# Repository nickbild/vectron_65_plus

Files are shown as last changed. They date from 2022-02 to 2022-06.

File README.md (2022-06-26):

# Vectron 65 Plus

The Vectron 65 Plus is a 6502 CPU-based computer with keyboard support that can run BASIC.  It is highly extensible via 32 GPIO pins.

At present, I have built the following peripherals for the computer:
- [Vectron VGA Plus v2](https://github.com/nickbild/vectron_vga_plus_v2) - VGA output with pixel-level control
- [Vectron VGA Plus Text Mode](https://github.com/nickbild/vectron_vga_plus_text_mode) - Add-on for Vectron VGA Plus v2 that simplifies displaying text on screen
- [Vectron Sound Plus](https://github.com/nickbild/vectron_sound_plus) - Audio output with the AY-3-8910 sound generator chip

Read on for demonstrations of each of these add-ons.

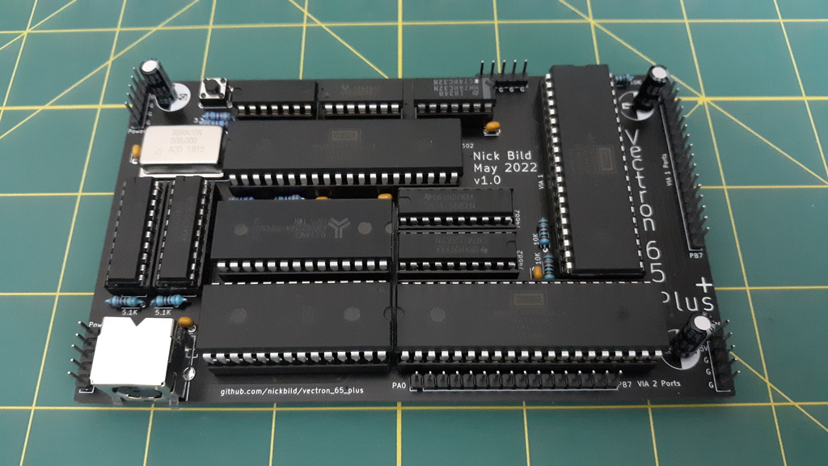
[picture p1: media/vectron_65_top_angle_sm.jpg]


This is an enhanced version of my [Vectron 65](https://github.com/nickbild/vectron_65) computer.

## How It Works

At the heart of the system is a WDC 65C02 CPU running at 8 MHz.  32 KB of SRAM is available, and a 32 KB ROM chip stores the program to execute (you can burn the ROM with [my Arduino code](https://github.com/nickbild/eeprom_burner_mega)).  A pair of 6522 VIA chips add a total of 32 GPIO pins to interface with external peripherals.  A PS/2 connector is present to support a keyboard (or a mouse, in theory, though I haven't tried one yet) — the clock and data lines are routed to GPIO pins.

This is the circuit design:



## Media

Here, the Vectron 65 Plus (left) is running TinyBASIC.  On the right, [Vectron VGA Plus Text Mode](https://github.com/nickbild/vectron_vga_plus_text_mode) is stacked on top of [Vectron VGA Plus v2](https://github.com/nickbild/vectron_vga_plus_v2) to provide a text mode VGA display output ([6502 code here](https://github.com/nickbild/vectron_65_plus/blob/main/os_vvga.asm)):

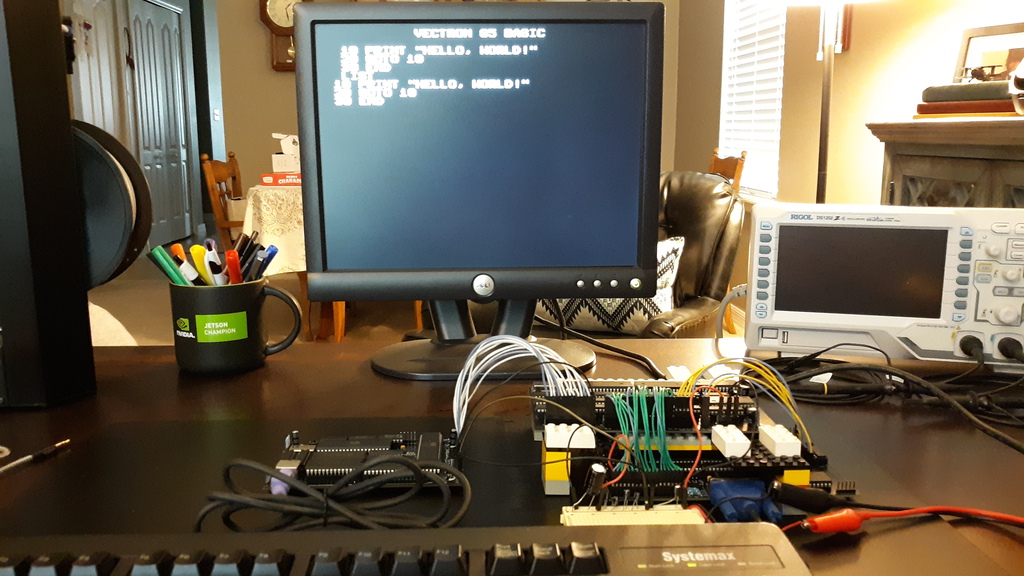
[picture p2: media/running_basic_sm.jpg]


In this example, the Vectron 65 Plus (right) is hooked up to [Vectron VGA Plus v2](https://github.com/nickbild/vectron_vga_plus_v2) to output some bitmap graphics ([6502 code here](https://github.com/nickbild/vectron_65_plus/blob/main/pacman.asm)):

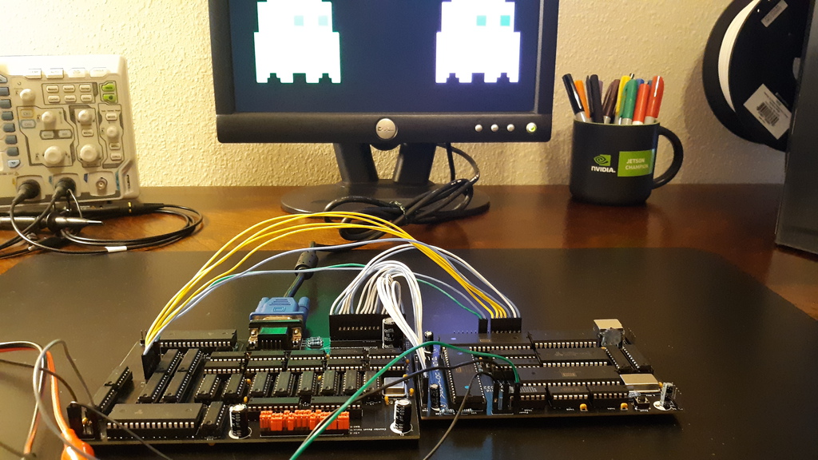
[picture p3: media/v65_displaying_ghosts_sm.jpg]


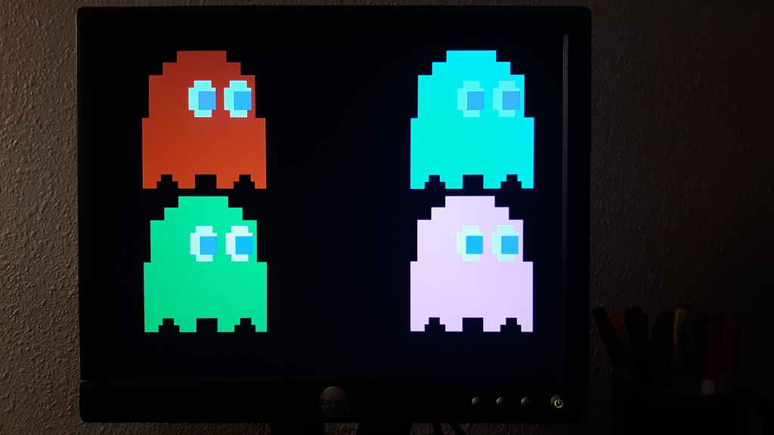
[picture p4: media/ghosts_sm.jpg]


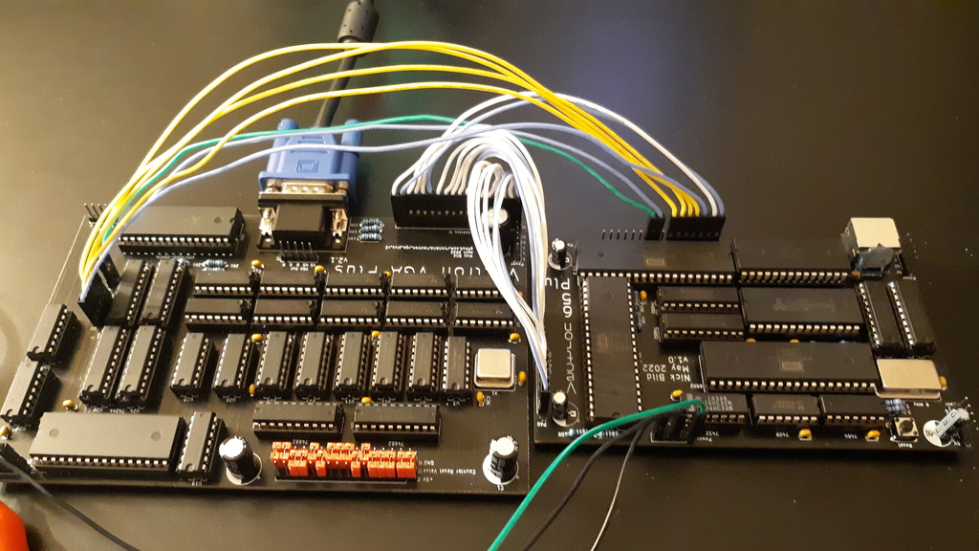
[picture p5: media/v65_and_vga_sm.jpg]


And for audio, I added in the [Vectron Sound Plus](https://github.com/nickbild/vectron_sound_plus) module:



You can download an [MP3 here](https://github.com/nickbild/vectron_sound_plus/blob/main/media/vectron_65_audio.mp3?raw=true) of a tune I made with it.

And a few more pictures:

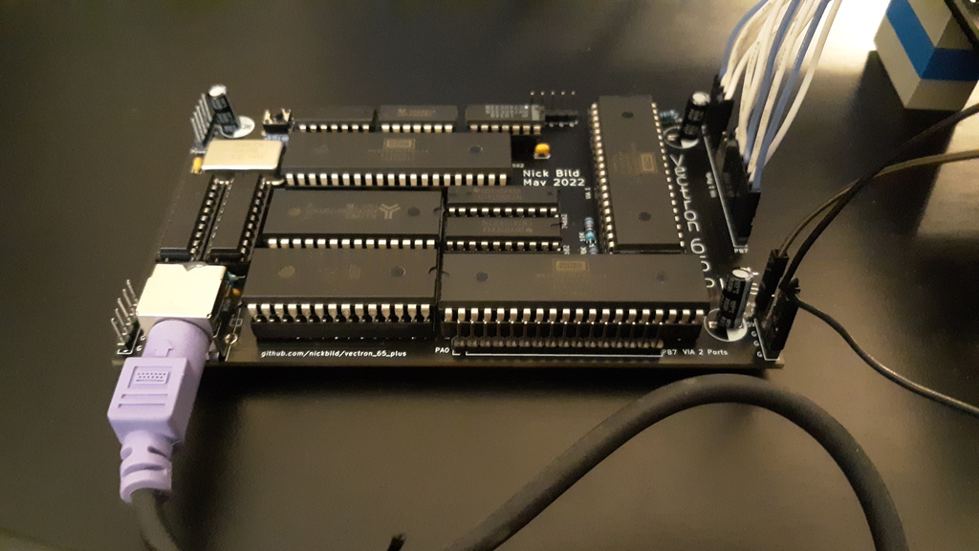
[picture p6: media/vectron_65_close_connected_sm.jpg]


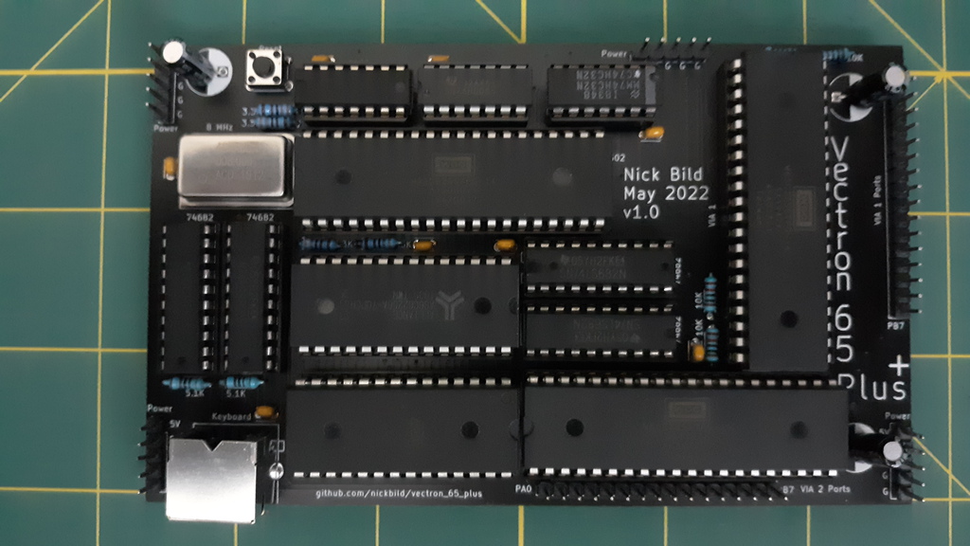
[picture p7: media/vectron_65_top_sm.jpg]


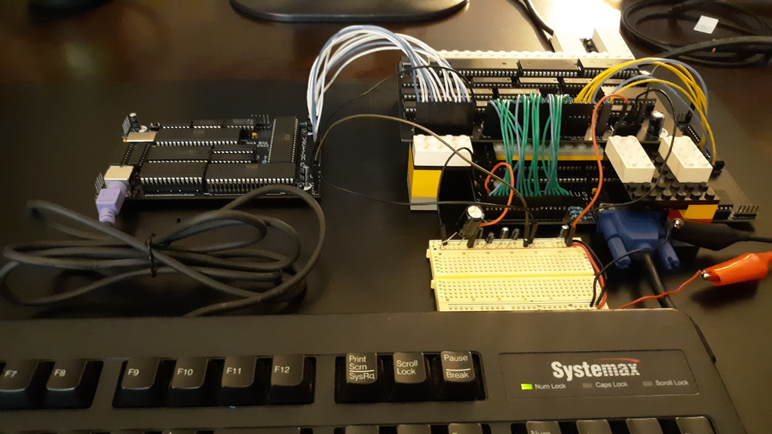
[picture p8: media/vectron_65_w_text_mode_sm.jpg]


## Bill of Materials

- 1 x 65C02 CPU
- 2 x 6522 VIA
- 1 x 28C256 ROM
- 1 x AS6C62256A RAM
- 4 x 74682
- 1 x 7404
- 1 x 7408
- 1 x 7432
- 1 x 8 MHz crystal oscillator
- 1 x push button
- 4 x 3.3K resistors
- 2 x 5.1K resistors
- 2 x 10K resistors
- 3 x 47 uF electrolytic capacitors
- 14 x 0.1 uF ceramic capacitors
- 1 x PS/2 connector
- 1 x PCB ([Kicad design file here](https://github.com/nickbild/vectron_65_plus/tree/main/kicad_vectron_65_plus))

## About the Author

[Nick A. Bild, MS](https://nickbild79.firebaseapp.com/#!/)

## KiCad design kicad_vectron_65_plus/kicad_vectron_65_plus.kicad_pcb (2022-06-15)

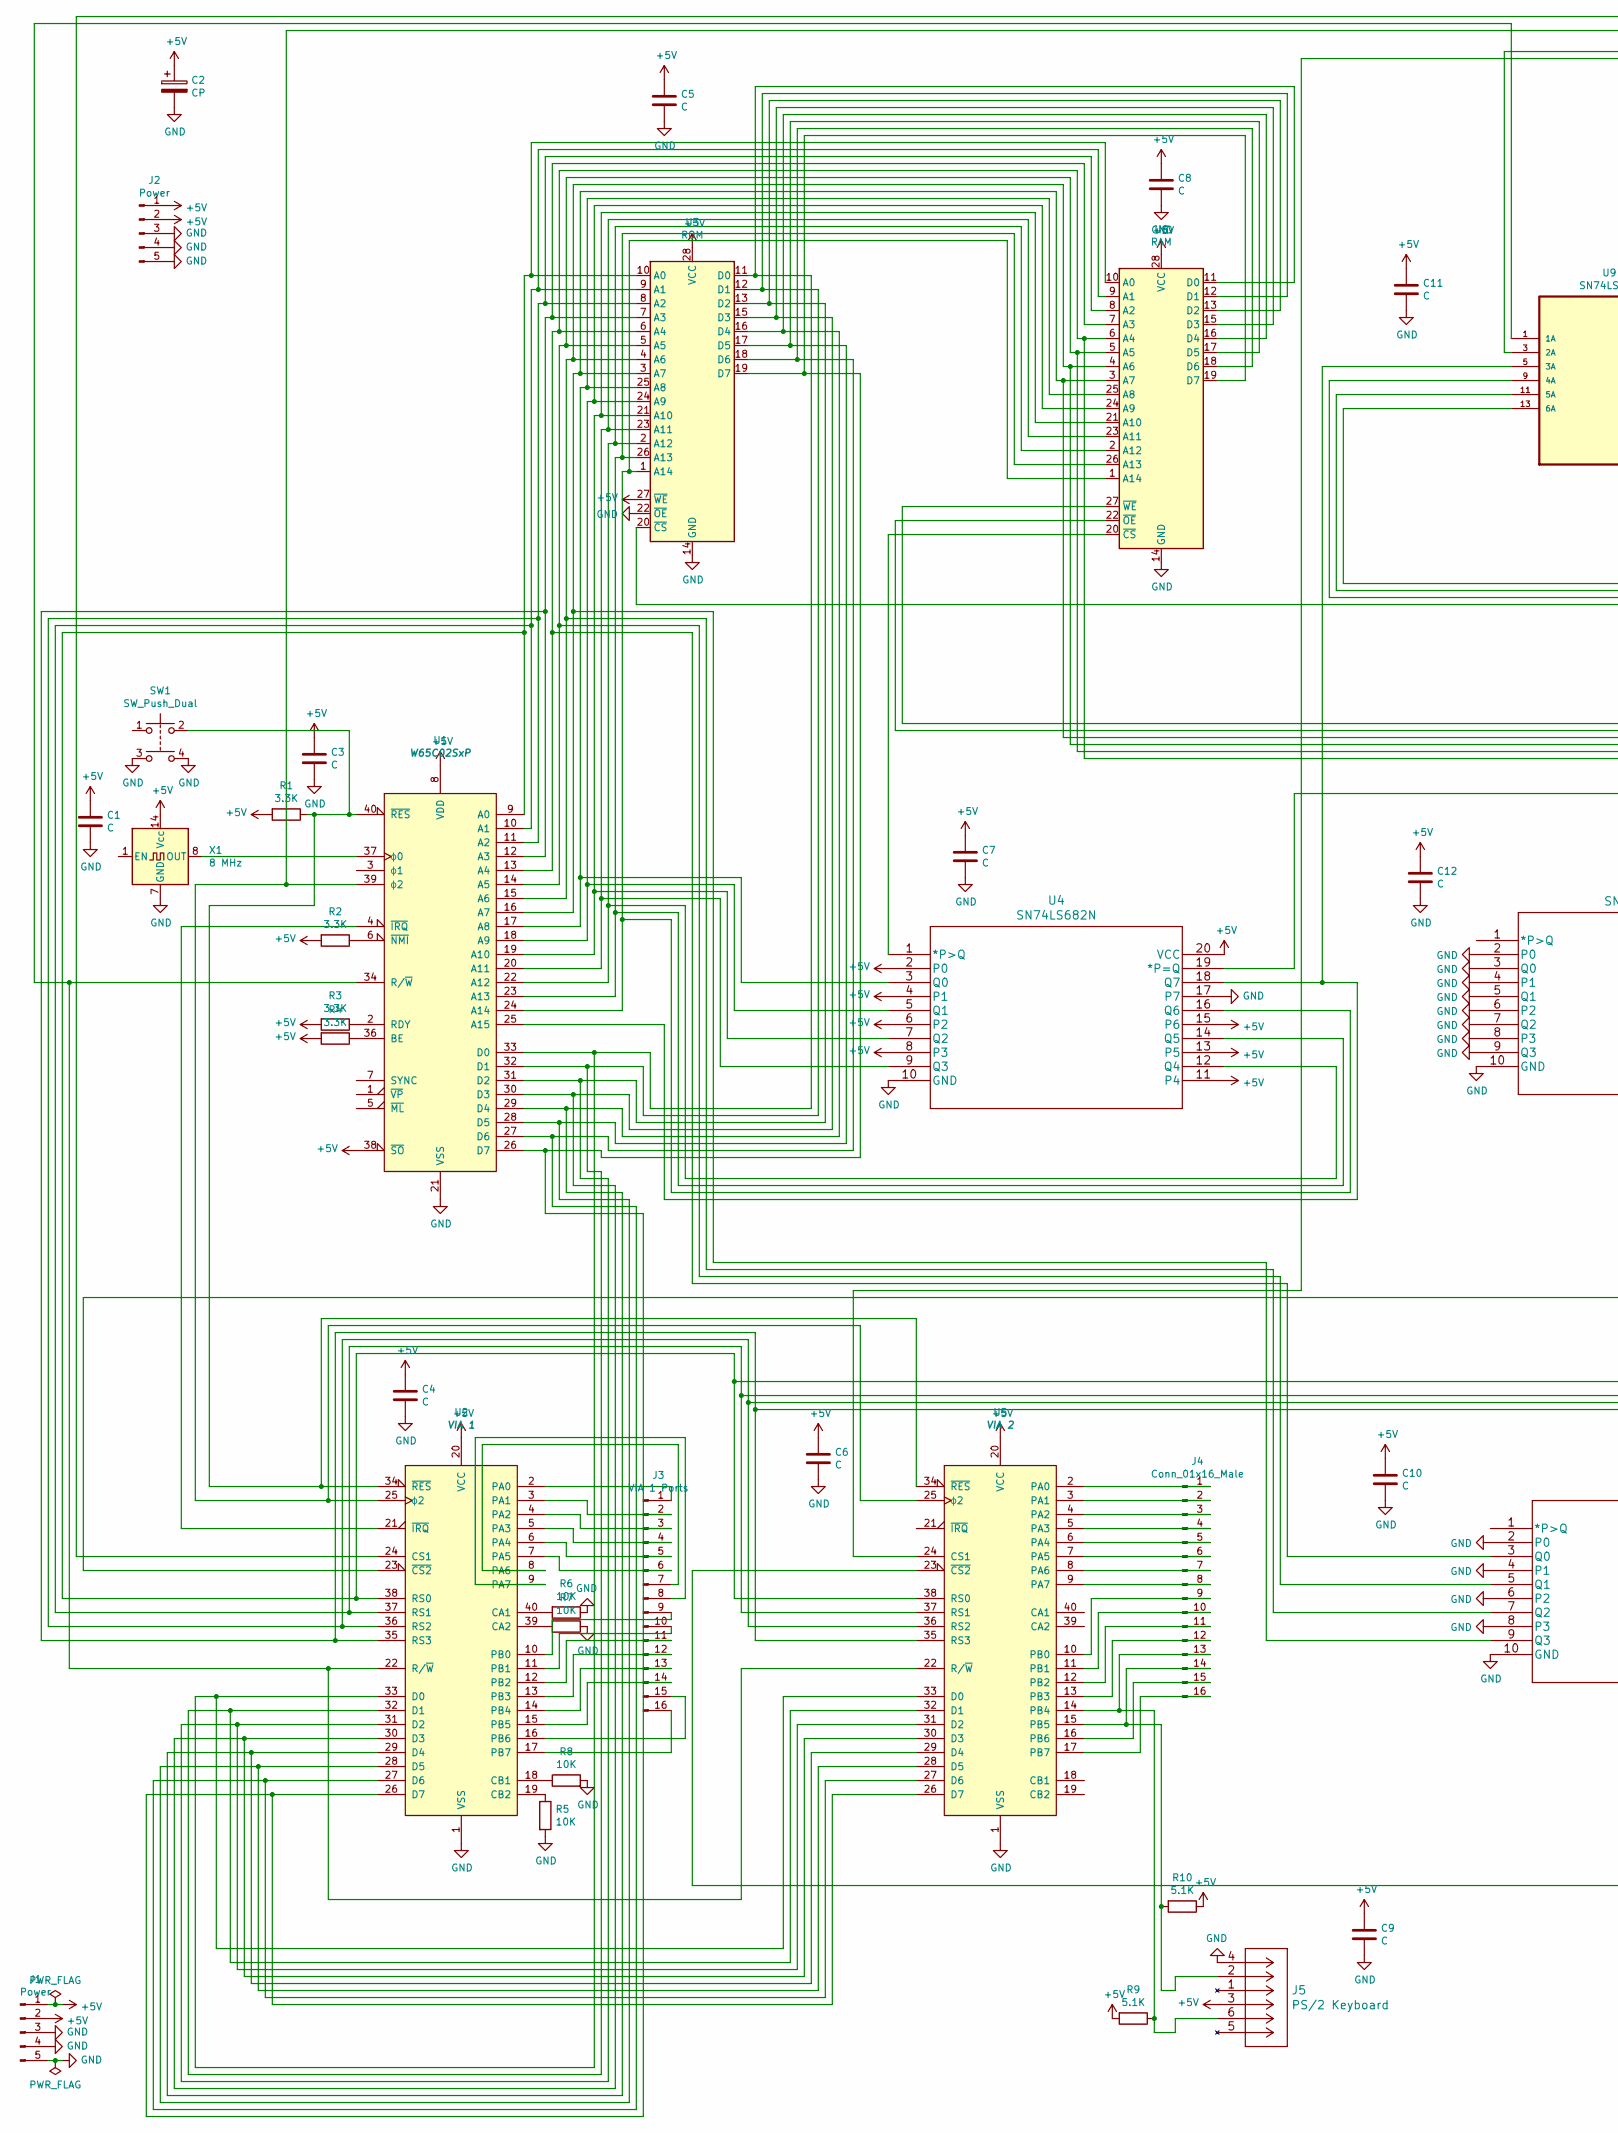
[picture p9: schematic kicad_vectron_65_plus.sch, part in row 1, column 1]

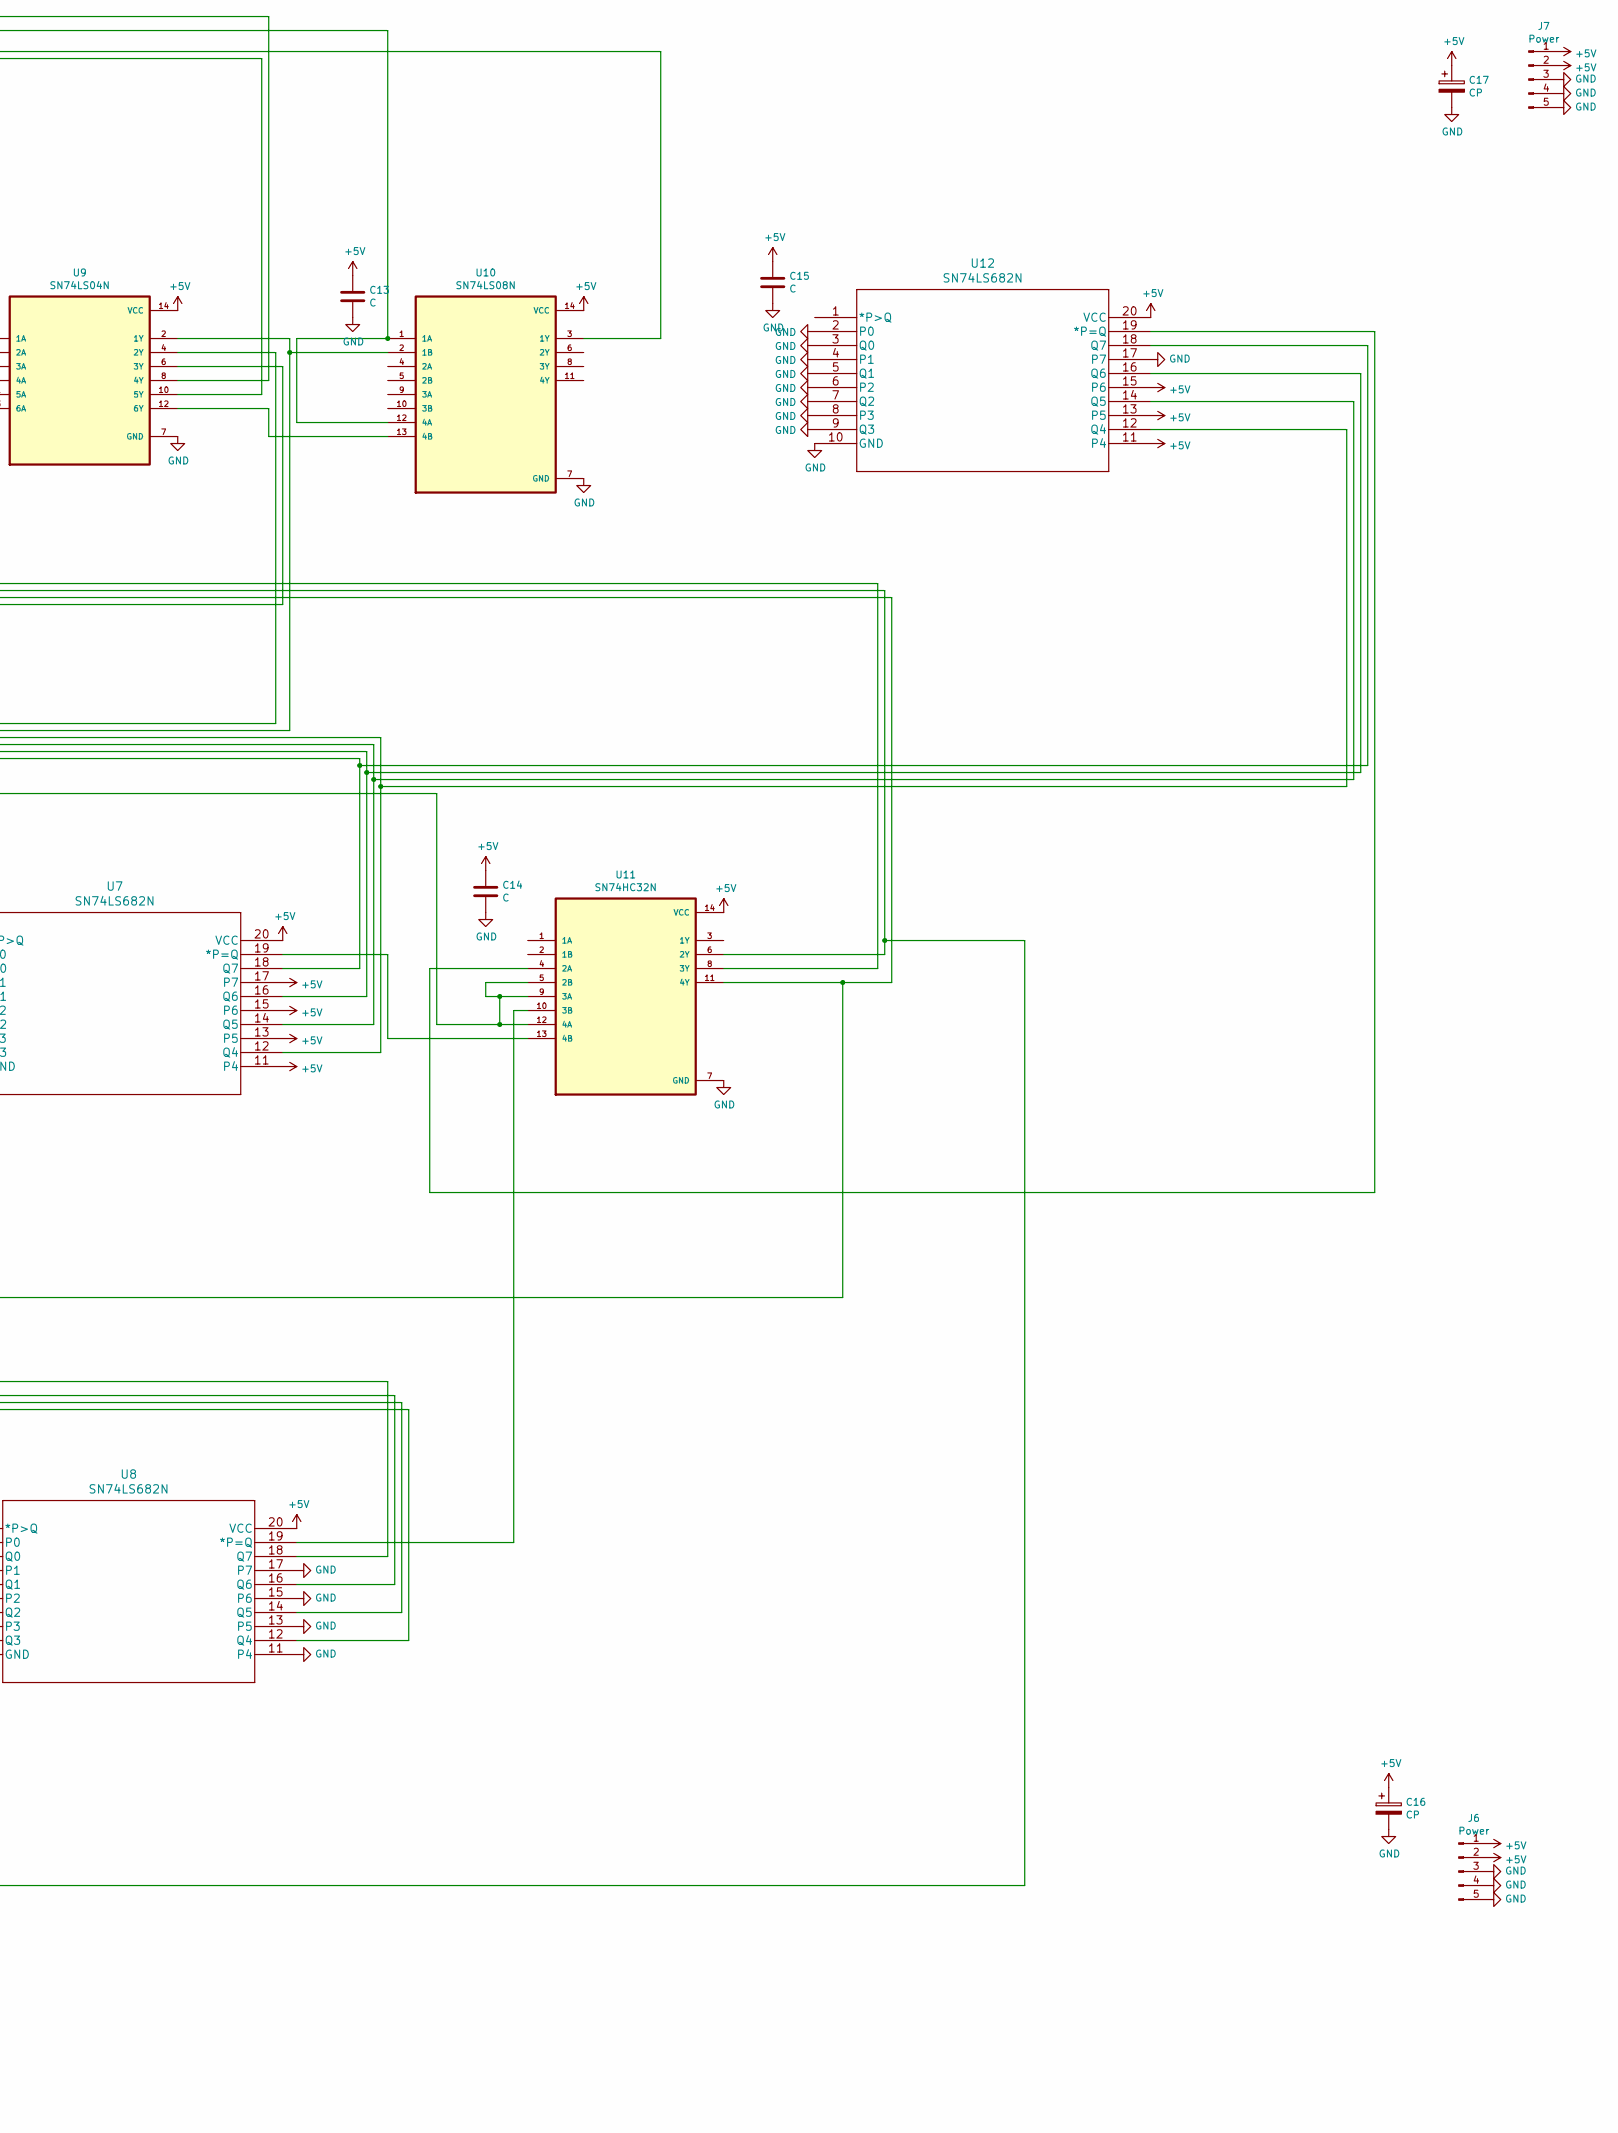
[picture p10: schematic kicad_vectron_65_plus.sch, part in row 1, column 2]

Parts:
C1, C3, C4, C5, C6, C7, C8, C9, C10, C11, C12, C13, C14, C15: C; C_Disc_D3.0mm_W2.0mm_P2.50mm
C2, C16, C17: CP; CP_Radial_D8.0mm_P5.00mm
J1, J2, J6, J7: Power; PinHeader_1x05_P2.54mm_Vertical
J3: VIA 1 Ports; PinHeader_1x16_P2.54mm_Vertical
J4: Conn_01x16_Male; PinHeader_1x16_P2.54mm_Vertical
J5: PS/2 Keyboard; 5750071-1
R1, R2, R3, R4: 3.3K; R_Axial_DIN0204_L3.6mm_D1.6mm_P5.08mm_Horizontal
R5, R6, R7, R8: 10K; R_Axial_DIN0204_L3.6mm_D1.6mm_P5.08mm_Horizontal
R9, R10: 5.1K; R_Axial_DIN0204_L3.6mm_D1.6mm_P5.08mm_Horizontal
SW1: SW_Push_Dual; SW_TH_Tactile_Omron_B3F-10xx
U1: W65C02SxP; DIP-40_W15.24mm
U2: VIA 1; DIP-40_W15.24mm
U3: ROM; DIP-28_W15.24mm
U4, U7, U8, U12: SN74LS682N; DIP-20_W7.62mm
U5: VIA 2; DIP-40_W15.24mm
U6: RAM; DIP-28_W15.24mm
U9: SN74LS04N; DIP-14_W7.62mm
U10: SN74LS08N; DIP-14_W7.62mm
U11: SN74HC32N; DIP-14_W7.62mm
X1: 8 MHz; Oscillator_DIP-14

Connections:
+5V: C1.1, C2.1, C3.1, C4.1, C5.1, C6.1, C7.1, C8.1, C9.1, C10.1, C11.1, C12.1, C13.1, C14.1, C15.1, C16.1, C17.1, J1.1, J1.2, J2.1, J2.2, J5.3, J6.1, J6.2, J7.1, J7.2, R1.2, R2.2, R3.2, R4.2, R9.2, R10.1, U1.8 (VDD), U1.38 (~SO), U2.20 (VCC), U3.27 (~WE), U3.28 (VCC), U4.2 (P0), U4.4 (P1), U4.6 (P2), U4.8 (P3), U4.11 (P4), U4.13 (P5), U4.15 (P6), U4.20 (VCC), U5.20 (VCC), U6.28 (VCC), U7.11 (P4), U7.13 (P5), U7.15 (P6), U7.17 (P7), U7.20 (VCC), U8.20 (VCC), U9.14 (VCC), U10.14 (VCC), U11.14 (VCC), U12.11 (P4), U12.13 (P5), U12.15 (P6), U12.20 (VCC), X1.14 (Vcc)
GND: C1.2, C2.2, C3.2, C4.2, C5.2, C6.2, C7.2, C8.2, C9.2, C10.2, C11.2, C12.2, C13.2, C14.2, C15.2, C16.2, C17.2, J1.3, J1.4, J1.5, J2.3, J2.4, J2.5, J5.4, J6.3, J6.4, J6.5, J7.3, J7.4, J7.5, R5.2, R6.1, R7.1, R8.2, SW1.3, SW1.4, U1.21 (VSS), U2.1 (VSS), U3.14 (GND), U3.22 (~OE), U4.10 (GND), U4.17 (P7), U5.1 (VSS), U6.14 (GND), U7.2 (P0), U7.3 (Q0), U7.4 (P1), U7.5 (Q1), U7.6 (P2), U7.7 (Q2), U7.8 (P3), U7.9 (Q3), U7.10 (GND), U8.2 (P0), U8.4 (P1), U8.6 (P2), U8.8 (P3), U8.10 (GND), U8.11 (P4), U8.13 (P5), U8.15 (P6), U8.17 (P7), U9.7 (GND), U10.7 (GND), U11.7 (GND), U12.2 (P0), U12.3 (Q0), U12.4 (P1), U12.5 (Q1), U12.6 (P2), U12.7 (Q2), U12.8 (P3), U12.9 (Q3), U12.10 (GND), U12.17 (P7), X1.7 (GND)
unnamed: J3.1, U2.2 (PA0)
unnamed: J3.2, U2.3 (PA1)
unnamed: J3.3, U2.4 (PA2)
unnamed: J3.4, U2.5 (PA3)
unnamed: J3.5, U2.6 (PA4)
unnamed: J3.6, U2.7 (PA5)
unnamed: J3.7, U2.8 (PA6)
unnamed: J3.8, U2.9 (PA7)
unnamed: J3.9, U2.10 (PB0)
unnamed: J3.10, U2.11 (PB1)
unnamed: J3.11, U2.12 (PB2)
unnamed: J3.12, U2.13 (PB3)
unnamed: J3.13, U2.14 (PB4)
unnamed: J3.14, U2.15 (PB5)
unnamed: J3.15, U2.16 (PB6)
unnamed: J3.16, U2.17 (PB7)
unnamed: J4.1, U5.2 (PA0)
unnamed: J4.2, U5.3 (PA1)
unnamed: J4.3, U5.4 (PA2)
unnamed: J4.4, U5.5 (PA3)
unnamed: J4.5, U5.6 (PA4)
unnamed: J4.6, U5.7 (PA5)
unnamed: J4.7, U5.8 (PA6)
unnamed: J4.8, U5.9 (PA7)
unnamed: J4.9, U5.10 (PB0)
unnamed: J4.10, U5.11 (PB1)
unnamed: J4.11, U5.12 (PB2)
unnamed: J4.12, U5.13 (PB3)
unnamed: J4.13, J5.6, R9.1, U5.14 (PB4)
unnamed: J4.14, J5.2, R10.2, U5.15 (PB5)
unnamed: J4.15, U5.16 (PB6)
unnamed: J4.16, U5.17 (PB7)
unnamed: R1.1, SW1.2, U1.40 (~RES), U2.34 (~RES), U5.34 (~RES)
unnamed: R2.1, U1.6 (~NMI)
unnamed: R3.1, U1.2 (RDY)
unnamed: R4.1, U1.36 (BE)
unnamed: R5.1, U2.19 (CB2)
unnamed: R6.2, U2.40 (CA1)
unnamed: R7.2, U2.39 (CA2)
unnamed: R8.1, U2.18 (CB1)
unnamed: U1.4 (~IRQ), U2.21 (~IRQ)
unnamed: U1.9 (A0), U2.38 (RS0), U3.10 (A0), U5.38 (RS0), U6.10 (A0), U8.18 (Q7)
unnamed: U1.10 (A1), U2.37 (RS1), U3.9 (A1), U5.37 (RS1), U6.9 (A1), U8.16 (Q6)
unnamed: U1.11 (A2), U2.36 (RS2), U3.8 (A2), U5.36 (RS2), U6.8 (A2), U8.14 (Q5)
unnamed: U1.12 (A3), U2.35 (RS3), U3.7 (A3), U5.35 (RS3), U6.7 (A3), U8.12 (Q4)
unnamed: U1.13 (A4), U3.6 (A4), U6.6 (A4), U7.18 (Q7), U8.3 (Q0), U12.18 (Q7)
unnamed: U1.14 (A5), U3.5 (A5), U6.5 (A5), U7.16 (Q6), U8.5 (Q1), U12.16 (Q6)
unnamed: U1.15 (A6), U3.4 (A6), U6.4 (A6), U7.14 (Q5), U8.7 (Q2), U12.14 (Q5)
unnamed: U1.16 (A7), U3.3 (A7), U6.3 (A7), U7.12 (Q4), U8.9 (Q3), U12.12 (Q4)
unnamed: U1.17 (A8), U3.25 (A8), U4.3 (Q0), U6.25 (A8)
unnamed: U1.18 (A9), U3.24 (A9), U4.5 (Q1), U6.24 (A9)
unnamed: U1.19 (A10), U3.21 (A10), U4.7 (Q2), U6.21 (A10)
unnamed: U1.20 (A11), U3.23 (A11), U4.9 (Q3), U6.23 (A11)
unnamed: U1.22 (A12), U3.2 (A12), U4.12 (Q4), U6.2 (A12)
unnamed: U1.23 (A13), U3.26 (A13), U4.14 (Q5), U6.26 (A13)
unnamed: U1.24 (A14), U3.1 (A14), U4.16 (Q6), U6.1 (A14)
unnamed: U1.25 (A15), U4.18 (Q7), U9.5 (3A)
unnamed: U1.26 (D7), U2.26 (D7), U3.19 (D7), U5.26 (D7), U6.19 (D7)
unnamed: U1.27 (D6), U2.27 (D6), U3.18 (D6), U5.27 (D6), U6.18 (D6)
unnamed: U1.28 (D5), U2.28 (D5), U3.17 (D5), U5.28 (D5), U6.17 (D5)
unnamed: U1.29 (D4), U2.29 (D4), U3.16 (D4), U5.29 (D4), U6.16 (D4)
unnamed: U1.30 (D3), U2.30 (D3), U3.15 (D3), U5.30 (D3), U6.15 (D3)
unnamed: U1.31 (D2), U2.31 (D2), U3.13 (D2), U5.31 (D2), U6.13 (D2)
unnamed: U1.32 (D1), U2.32 (D1), U3.12 (D1), U5.32 (D1), U6.12 (D1)
unnamed: U1.33 (D0), U2.33 (D0), U3.11 (D0), U5.33 (D0), U6.11 (D0)
unnamed: U1.34 (R/~W), U2.22 (R/~W), U5.22 (R/~W), U9.1 (1A)
unnamed: U1.37 (ϕ0), X1.8 (OUT)
unnamed: U1.39 (ϕ2), U2.25 (ϕ2), U5.25 (ϕ2), U10.1 (1A), U10.12 (4A)
unnamed: U2.24 (CS1), U9.8 (4Y)
unnamed: U3.20 (~CS), U9.6 (3Y)
unnamed: U4.1 (*P>Q), U6.20 (~CS)
unnamed: U5.24 (CS1), U9.10 (5Y)
unnamed: U6.27 (~WE), U9.4 (2Y)
unnamed: U6.22 (~OE), U9.2 (1Y), U10.2 (1B)
unnamed: U9.3 (2A), U10.3 (1Y)
unnamed: U9.12 (6Y), U10.13 (4B)
unnamed: U11.4 (2A), U12.19 (*P=Q)
unnamed: U5.23 (~CS2), U9.11 (5A), U11.6 (2Y)
unnamed: U9.13 (6A), U11.8 (3Y)
unnamed: U8.19 (*P=Q), U11.10 (3B)
unnamed: U2.23 (~CS2), U9.9 (4A), U11.11 (4Y)
unnamed: U4.19 (*P=Q), U11.5 (2B), U11.9 (3A), U11.12 (4A)
unnamed: U7.19 (*P=Q), U11.13 (4B)

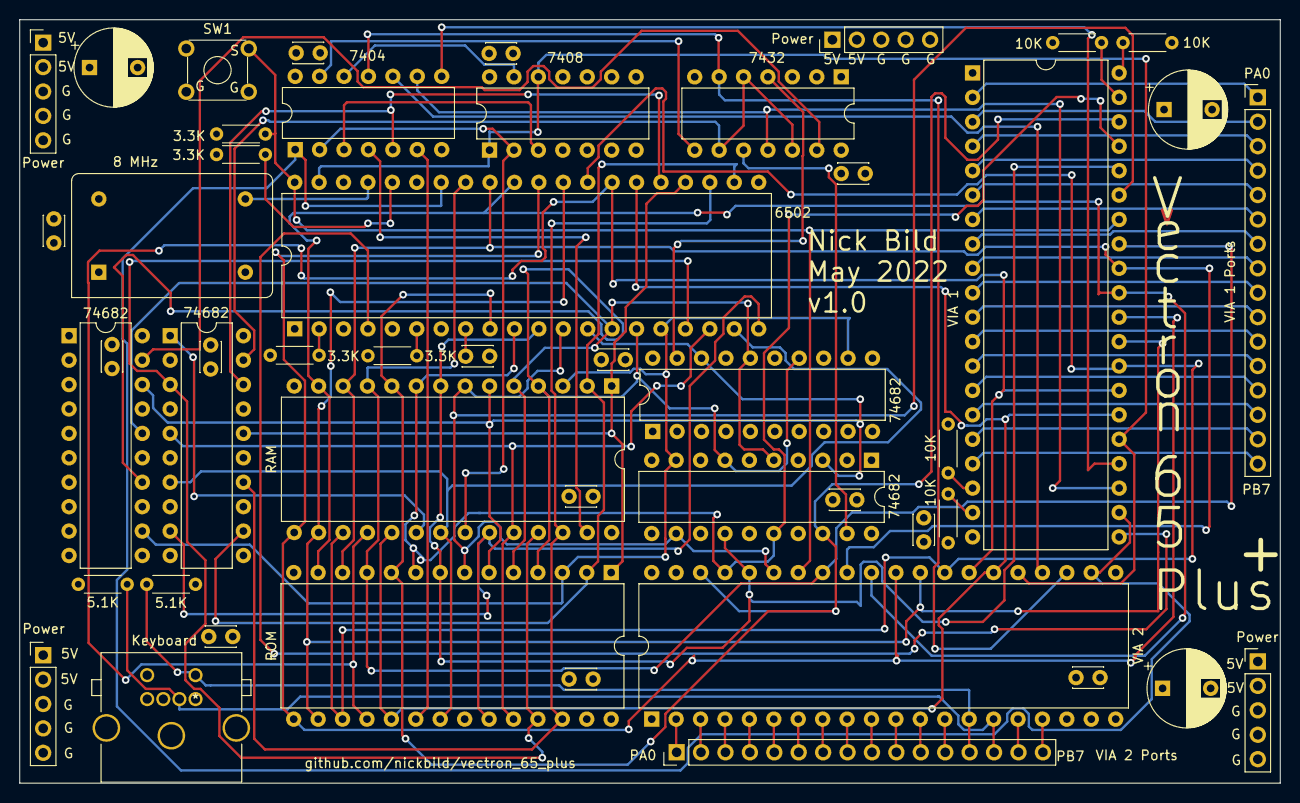
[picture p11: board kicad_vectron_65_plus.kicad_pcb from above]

Board: 4 copper layers, 131.1 x 79.4 mm, 48 parts (0 on the bottom side), 85 nets.

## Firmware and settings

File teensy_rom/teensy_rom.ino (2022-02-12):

/*
Pin |  GPIO Reg  |  PWM timer
----|------------|-------------
01  |  GPIO6_02  |  FLEX_PWM1 
00  |  GPIO6_03  |  FLEX_PWM1 
24  |  GPIO6_12  |  FLEX_PWM1 
25  |  GPIO6_13  |  FLEX_PWM1 
19  |  GPIO6_16  |  QUAD3     
18  |  GPIO6_17  |  QUAD3     
14  |  GPIO6_18  |  QUAD3     
15  |  GPIO6_19  |  QUAD3     
17  |  GPIO6_22  |  no pwm    
16  |  GPIO6_23  |  no pwm    
22  |  GPIO6_24  |  FLEX_PWM4 
23  |  GPIO6_25  |  FLEX_PWM4 
20  |  GPIO6_26  |  no pwm    
21  |  GPIO6_27  |  no pwm    
26  |  GPIO6_30  |  no pwm    
27  |  GPIO6_31  |  no pwm    
10  |  GPIO7_00  |  QUAD1     
12  |  GPIO7_01  |  QUAD1     
11  |  GPIO7_02  |  QUAD1     
13  |  GPIO7_03  |  QUAD2     
06  |  GPIO7_10  |  FLEX_PWM2 
09  |  GPIO7_11  |  FLEX_PWM2 
32  |  GPIO7_12  |  no pwm    
08  |  GPIO7_16  |  FLEX_PWM1 
07  |  GPIO7_17  |  FLEX_PWM1 
37  |  GPIO8_12  |  FLEX_PWM1 
36  |  GPIO8_13  |  FLEX_PWM1 
35  |  GPIO8_14  |  FLEX_PWM1 
34  |  GPIO8_15  |  FLEX_PWM1 
39  |  GPIO8_16  |  FLEX_PWM1 
38  |  GPIO8_17  |  FLEX_PWM1 
28  |  GPIO8_18  |  FLEX_PWM3 
31  |  GPIO8_22  |  no pwm    
30  |  GPIO8_23  |  no pwm    
02  |  GPIO9_04  |  FLEX_PWM4 
03  |  GPIO9_05  |  FLEX_PWM4 
04  |  GPIO9_06  |  FLEX_PWM2 
33  |  GPIO9_07  |  FLEX_PWM2 
05  |  GPIO9_08  |  FLEX_PWM2 
29  |  GPIO9_31  |  FLEX_PWM3 
*/

uint32_t rom_contents[32768] = {};
uint16_t addr;
uint16_t temp;

void setup() {
  // Address bus.  A0-A14.
  pinMode(1, INPUT);
  pinMode(0, INPUT);
  pinMode(24, INPUT);
  pinMode(25, INPUT);
  pinMode(19, INPUT);
  pinMode(18, INPUT);
  pinMode(14, INPUT);
  pinMode(15, INPUT);
  pinMode(17, INPUT);
  pinMode(16, INPUT);
  pinMode(22, INPUT);
  pinMode(23, INPUT);
  pinMode(20, INPUT);
  pinMode(21, INPUT);
  pinMode(26, INPUT);

  // Data bus.  D0-D7.
  pinMode(10, OUTPUT);
  pinMode(12, OUTPUT);
  pinMode(11, OUTPUT);
  pinMode(13, OUTPUT);
  pinMode(6, OUTPUT);
  pinMode(9, OUTPUT);
  pinMode(32, OUTPUT);
  pinMode(8, OUTPUT);

  // Populate simulated ROM.
  setup_rom_contents();
}

void loop() {
  // Stitch address together from register bits.
  // GPIO6: xAxxAAAAAAxxAAAAxxAAxxxxxxxxAAxx
  addr = (GPIO6_DR & (1 << 30)) >> 30;

  addr = addr << 6;
  temp = (GPIO6_DR & (63 << 22)) >> 22;
  addr = addr + temp;
  
  addr = addr << 4;
  temp = (GPIO6_DR & (15 << 16)) >> 16;
  addr = addr + temp;
  
  addr = addr << 2;
  temp = (GPIO6_DR & (3 << 12)) >> 12;
  addr = addr + temp;
  
  addr = addr << 2;
  temp = (GPIO6_DR & (3 << 2)) >> 2;
  addr = addr + temp;

  // Set data bus.
  GPIO7_DR = rom_contents[addr];
}

void setup_rom_contents() {
  // ROM contents values must be preprocessed to fit into GPIO7.
  // (bit 8) DxxxDDDxxxxxxDDDD (bit 0)
  
  // NMI Interrupt address.
  // little endian
  rom_contents[32762] = 0;
  rom_contents[32763] = 0;

  // Starting address of program (write to FFFC-FFFD).
  // little endian
  rom_contents[32764] = 0;
  rom_contents[32765] = 65536; // 128

  // Interrupt address.
  // little endian
  rom_contents[32766] = 0;
  rom_contents[32767] = 0;

   // Program, starting at ROM address 0.
	rom_contents[0] = 7176;		// Actual: 120
	rom_contents[1] = 67593;		// Actual: 169
	rom_contents[2] = 7183;		// Actual: 127
	rom_contents[3] = 65549;		// Actual: 141
	rom_contents[4] = 72718;		// Actual: 254
	rom_contents[5] = 7183;		// Actual: 127
	rom_contents[6] = 67593;		// Actual: 169
	rom_contents[7] = 72719;		// Actual: 255
	rom_contents[8] = 65549;		// Actual: 141
	rom_contents[9] = 72706;		// Actual: 242
	rom_contents[10] = 7183;		// Actual: 127
	rom_contents[11] = 67593;		// Actual: 169
	rom_contents[12] = 72719;		// Actual: 255
	rom_contents[13] = 65549;		// Actual: 141
	rom_contents[14] = 72707;		// Actual: 243
	rom_contents[15] = 7183;		// Actual: 127
	rom_contents[16] = 67593;		// Actual: 169
	rom_contents[17] = 0;		// Actual: 0
	rom_contents[18] = 65549;		// Actual: 141
	rom_contents[19] = 72704;		// Actual: 240
	rom_contents[20] = 7183;		// Actual: 127
	rom_contents[21] = 67593;		// Actual: 169
	rom_contents[22] = 0;		// Actual: 0
	rom_contents[23] = 65549;		// Actual: 141
	rom_contents[24] = 72705;		// Actual: 241
	rom_contents[25] = 7183;		// Actual: 127
	rom_contents[26] = 67593;		// Actual: 169
	rom_contents[27] = 7183;		// Actual: 127
	rom_contents[28] = 65549;		// Actual: 141
	rom_contents[29] = 71694;		// Actual: 238
	rom_contents[30] = 7183;		// Actual: 127
	rom_contents[31] = 67593;		// Actual: 169
	rom_contents[32] = 72719;		// Actual: 255
	rom_contents[33] = 65549;		// Actual: 141
	rom_contents[34] = 71683;		// Actual: 227
	rom_contents[35] = 7183;		// Actual: 127
	rom_contents[36] = 67593;		// Actual: 169
	rom_contents[37] = 0;		// Actual: 0
	rom_contents[38] = 65549;		// Actual: 141
	rom_contents[39] = 71681;		// Actual: 225
	rom_contents[40] = 7183;		// Actual: 127
	rom_contents[41] = 67593;		// Actual: 169
	rom_contents[42] = 3;		// Actual: 3
	rom_contents[43] = 12;		// Actual: 12
	rom_contents[44] = 71682;		// Actual: 226
	rom_contents[45] = 7183;		// Actual: 127
	rom_contents[46] = 67593;		// Actual: 169
	rom_contents[47] = 3;		// Actual: 3
	rom_contents[48] = 1036;		// Actual: 28
	rom_contents[49] = 71680;		// Actual: 224
	rom_contents[50] = 7183;		// Actual: 127
	rom_contents[51] = 67593;		// Actual: 169
	rom_contents[52] = 7;		// Actual: 7
	rom_contents[53] = 65549;		// Actual: 141
	rom_contents[54] = 71681;		// Actual: 225
	rom_contents[55] = 7183;		// Actual: 127
	rom_contents[56] = 2048;		// Actual: 32
	rom_contents[57] = 66571;		// Actual: 155
	rom_contents[58] = 65537;		// Actual: 129
	rom_contents[59] = 2048;		// Actual: 32
	rom_contents[60] = 65551;		// Actual: 143
	rom_contents[61] = 65537;		// Actual: 129
	rom_contents[62] = 67593;		// Actual: 169
	rom_contents[63] = 3080;		// Actual: 56
	rom_contents[64] = 65549;		// Actual: 141
	rom_contents[65] = 71681;		// Actual: 225
	rom_contents[66] = 7183;		// Actual: 127
	rom_contents[67] = 2048;		// Actual: 32
	rom_contents[68] = 66565;		// Actual: 149
	rom_contents[69] = 65537;		// Actual: 129
	rom_contents[70] = 2048;		// Actual: 32
	rom_contents[71] = 65551;		// Actual: 143
	rom_contents[72] = 65537;		// Actual: 129
	rom_contents[73] = 67593;		// Actual: 169
	rom_contents[74] = 8;		// Actual: 8
	rom_contents[75] = 65549;		// Actual: 141
	rom_contents[76] = 71681;		// Actual: 225
	rom_contents[77] = 7183;		// Actual: 127
	rom_contents[78] = 2048;		// Actual: 32
	rom_contents[79] = 66571;		// Actual: 155
	rom_contents[80] = 65537;		// Actual: 129
	rom_contents[81] = 2048;		// Actual: 32
	rom_contents[82] = 65551;		// Actual: 143
	rom_contents[83] = 65537;		// Actual: 129
	rom_contents[84] = 67593;		// Actual: 169
	rom_contents[85] = 5;		// Actual: 5
	rom_contents[86] = 65549;		// Actual: 141
	rom_contents[87] = 71681;		// Actual: 225
	rom_contents[88] = 7183;		// Actual: 127
	rom_contents[89] = 2048;		// Actual: 32
	rom_contents[90] = 66565;		// Actual: 149
	rom_contents[91] = 65537;		// Actual: 129
	rom_contents[92] = 2048;		// Actual: 32
	rom_contents[93] = 65551;		// Actual: 143
	rom_contents[94] = 65537;		// Actual: 129
	rom_contents[95] = 67593;		// Actual: 169
	rom_contents[96] = 9;		// Actual: 9
	rom_contents[97] = 65549;		// Actual: 141
	rom_contents[98] = 71681;		// Actual: 225
	rom_contents[99] = 7183;		// Actual: 127
	rom_contents[100] = 2048;		// Actual: 32
	rom_contents[101] = 66571;		// Actual: 155
	rom_contents[102] = 65537;		// Actual: 129
	rom_contents[103] = 2048;		// Actual: 32
	rom_contents[104] = 65551;		// Actual: 143
	rom_contents[105] = 65537;		// Actual: 129
	rom_contents[106] = 67593;		// Actual: 169
	rom_contents[107] = 5;		// Actual: 5
	rom_contents[108] = 65549;		// Actual: 141
	rom_contents[109] = 71681;		// Actual: 225
	rom_contents[110] = 7183;		// Actual: 127
	rom_contents[111] = 2048;		// Actual: 32
	rom_contents[112] = 66565;		// Actual: 149
	rom_contents[113] = 65537;		// Actual: 129
	rom_contents[114] = 2048;		// Actual: 32
	rom_contents[115] = 65551;		// Actual: 143
	rom_contents[116] = 65537;		// Actual: 129
	rom_contents[117] = 2048;		// Actual: 32
	rom_contents[118] = 67585;		// Actual: 161
	rom_contents[119] = 65537;		// Actual: 129
	rom_contents[120] = 67593;		// Actual: 169
	rom_contents[121] = 8;		// Actual: 8
	rom_contents[122] = 65549;		// Actual: 141
	rom_contents[123] = 71681;		// Actual: 225
	rom_contents[124] = 7183;		// Actual: 127
	rom_contents[125] = 2048;		// Actual: 32
	rom_contents[126] = 66571;		// Actual: 155
	rom_contents[127] = 65537;		// Actual: 129
	rom_contents[128] = 2048;		// Actual: 32
	rom_contents[129] = 65551;		// Actual: 143
	rom_contents[130] = 65537;		// Actual: 129
	rom_contents[131] = 67593;		// Actual: 169
	rom_contents[132] = 0;		// Actual: 0
	rom_contents[133] = 65549;		// Actual: 141
	rom_contents[134] = 71681;		// Actual: 225
	rom_contents[135] = 7183;		// Actual: 127
	rom_contents[136] = 2048;		// Actual: 32
	rom_contents[137] = 66565;		// Actual: 149
	rom_contents[138] = 65537;		// Actual: 129
	rom_contents[139] = 2048;		// Actual: 32
	rom_contents[140] = 65551;		// Actual: 143
	rom_contents[141] = 65537;		// Actual: 129
	rom_contents[142] = 67593;		// Actual: 169
	rom_contents[143] = 9;		// Actual: 9
	rom_contents[144] = 65549;		// Actual: 141
	rom_contents[145] = 71681;		// Actual: 225
	rom_contents[146] = 7183;		// Actual: 127
	rom_contents[147] = 2048;		// Actual: 32
	rom_contents[148] = 66571;		// Actual: 155
	rom_contents[149] = 65537;		// Actual: 129
	rom_contents[150] = 2048;		// Actual: 32
	rom_contents[151] = 65551;		// Actual: 143
	rom_contents[152] = 65537;		// Actual: 129
	rom_contents[153] = 67593;		// Actual: 169
	rom_contents[154] = 0;		// Actual: 0
	rom_contents[155] = 65549;		// Actual: 141
	rom_contents[156] = 71681;		// Actual: 225
	rom_contents[157] = 7183;		// Actual: 127
	rom_contents[158] = 2048;		// Actual: 32
	rom_contents[159] = 66565;		// Actual: 149
	rom_contents[160] = 65537;		// Actual: 129
	rom_contents[161] = 2048;		// Actual: 32
	rom_contents[162] = 65551;		// Actual: 143
	rom_contents[163] = 65537;		// Actual: 129
	rom_contents[164] = 2048;		// Actual: 32
	rom_contents[165] = 70667;		// Actual: 219
	rom_contents[166] = 65545;		// Actual: 137
	rom_contents[167] = 2048;		// Actual: 32
	rom_contents[168] = 66561;		// Actual: 145
	rom_contents[169] = 65540;		// Actual: 132
	rom_contents[170] = 67593;		// Actual: 169
	rom_contents[171] = 1;		// Actual: 1
	rom_contents[172] = 65541;		// Actual: 133
	rom_contents[173] = 4;		// Actual: 4
	rom_contents[174] = 67593;		// Actual: 169
	rom_contents[175] = 1;		// Actual: 1
	rom_contents[176] = 65541;		// Actual: 133
	rom_contents[177] = 5;		// Actual: 5
	rom_contents[178] = 67589;		// Actual: 165
	rom_contents[179] = 5;		// Actual: 5
	rom_contents[180] = 65549;		// Actual: 141
	rom_contents[181] = 72704;		// Actual: 240
	rom_contents[182] = 7183;		// Actual: 127
	rom_contents[183] = 67589;		// Actual: 165
	rom_contents[184] = 4;		// Actual: 4
	rom_contents[185] = 65549;		// Actual: 141
	rom_contents[186] = 72705;		// Actual: 241
	rom_contents[187] = 7183;		// Actual: 127
	rom_contents[188] = 5128;		// Actual: 88
	rom_contents[189] = 67586;		// Actual: 162
	rom_contents[190] = 0;		// Actual: 0
	rom_contents[191] = 2048;		// Actual: 32
	rom_contents[192] = 69637;		// Actual: 197
	rom_contents[193] = 65536;		// Actual: 128
	rom_contents[194] = 4108;		// Actual: 76
	rom_contents[195] = 66575;		// Actual: 159
	rom_contents[196] = 65547;		// Actual: 139
	rom_contents[197] = 68621;		// Actual: 189
	rom_contents[198] = 72704;		// Actual: 240
	rom_contents[199] = 66563;		// Actual: 147
	rom_contents[200] = 69641;		// Actual: 201
	rom_contents[201] = 72719;		// Actual: 255
	rom_contents[202] = 72704;		// Actual: 240
	rom_contents[203] = 7;		// Actual: 7
	rom_contents[204] = 2048;		// Actual: 32
	rom_contents[205] = 70671;		// Actual: 223
	rom_contents[206] = 65536;		// Actual: 128
	rom_contents[207] = 71688;		// Actual: 232
	rom_contents[208] = 4108;		// Actual: 76
	rom_contents[209] = 69637;		// Actual: 197
	rom_contents[210] = 65536;		// Actual: 128
	rom_contents[211] = 6144;		// Actual: 96
	rom_contents[212] = 2048;		// Actual: 32
	rom_contents[213] = 65548;		// Actual: 140
	rom_contents[214] = 65543;		// Actual: 135
	rom_contents[215] = 69641;		// Actual: 201
	rom_contents[216] = 13;		// Actual: 13
	rom_contents[217] = 70656;		// Actual: 208
	rom_contents[218] = 4;		// Actual: 4
	rom_contents[219] = 4104;		// Actual: 72
	rom_contents[220] = 4108;		// Actual: 76
	rom_contents[221] = 65547;		// Actual: 139
	rom_contents[222] = 65537;		// Actual: 129
	rom_contents[223] = 4104;		// Actual: 72
	rom_contents[224] = 69641;		// Actual: 201
	rom_contents[225] = 8;		// Actual: 8
	rom_contents[226] = 70656;		// Actual: 208
	rom_contents[227] = 3077;		// Actual: 53
	rom_contents[228] = 67593;		// Actual: 169
	rom_contents[229] = 2048;		// Actual: 32
	rom_contents[230] = 65549;		// Actual: 141
	rom_contents[231] = 0;		// Actual: 0
	rom_contents[232] = 7183;		// Actual: 127
	rom_contents[233] = 69638;		// Actual: 198
	rom_contents[234] = 4;		// Actual: 4
	rom_contents[235] = 67589;		// Actual: 165
	rom_contents[236] = 4;		// Actual: 4
	rom_contents[237] = 69641;		// Actual: 201
	rom_contents[238] = 0;		// Actual: 0
	rom_contents[239] = 70656;		// Actual: 208
	rom_contents[240] = 1025;		// Actual: 17
	rom_contents[241] = 67589;		// Actual: 165
	rom_contents[242] = 5;		// Actual: 5
	rom_contents[243] = 69641;		// Actual: 201
	rom_contents[244] = 1;		// Actual: 1
	rom_contents[245] = 72704;		// Actual: 240
	rom_contents[246] = 9;		// Actual: 9
	rom_contents[247] = 67593;		// Actual: 169
	rom_contents[248] = 3072;		// Actual: 48
	rom_contents[249] = 65541;		// Actual: 133
	rom_contents[250] = 4;		// Actual: 4
	rom_contents[251] = 69638;		// Actual: 198
	rom_contents[252] = 5;		// Actual: 5
	rom_contents[253] = 4108;		// Actual: 76
	rom_contents[254] = 2;		// Actual: 2
	rom_contents[255] = 65537;		// Actual: 129
	rom_contents[256] = 71686;		// Actual: 230
	rom_contents[257] = 4;		// Actual: 4
	rom_contents[258] = 67593;		// Actual: 169
	rom_contents[259] = 2048;		// Actual: 32
	rom_contents[260] = 65549;		// Actual: 141
	rom_contents[261] = 0;		// Actual: 0
	rom_contents[262] = 7183;		// Actual: 127
	rom_contents[263] = 67589;		// Actual: 165
	rom_contents[264] = 5;		// Actual: 5
	rom_contents[265] = 65549;		// Actual: 141
	rom_contents[266] = 72704;		// Actual: 240
	rom_contents[267] = 7183;		// Actual: 127
	rom_contents[268] = 67589;		// Actual: 165
	rom_contents[269] = 4;		// Actual: 4
	rom_contents[270] = 65549;		// Actual: 141
	rom_contents[271] = 72705;		// Actual: 241
	rom_contents[272] = 7183;		// Actual: 127
	rom_contents[273] = 67593;		// Actual: 169
	rom_contents[274] = 7183;		// Actual: 127
	rom_contents[275] = 65549;		// Actual: 141
	rom_contents[276] = 0;		// Actual: 0
	rom_contents[277] = 7183;		// Actual: 127
	rom_contents[278] = 4108;		// Actual: 76
	rom_contents[279] = 65547;		// Actual: 139
	rom_contents[280] = 65537;		// Actual: 129
	rom_contents[281] = 69641;		// Actual: 201
	rom_contents[282] = 11;		// Actual: 11
	rom_contents[283] = 66560;		// Actual: 144
	rom_contents[284] = 6158;		// Actual: 110
	rom_contents[285] = 69641;		// Actual: 201
	rom_contents[286] = 14;		// Actual: 14
	rom_contents[287] = 72704;		// Actual: 240
	rom_contents[288] = 6154;		// Actual: 106
	rom_contents[289] = 69641;		// Actual: 201
	rom_contents[290] = 1025;		// Actual: 17
	rom_contents[291] = 72704;		// Actual: 240
	rom_contents[292] = 6150;		// Actual: 102
	rom_contents[293] = 69641;		// Actual: 201
	rom_contents[294] = 65536;		// Actual: 128
	rom_contents[295] = 72704;		// Actual: 240
	rom_contents[296] = 6146;		// Actual: 98
	rom_contents[297] = 69641;		// Actual: 201
	rom_contents[298] = 66561;		// Actual: 145
	rom_contents[299] = 72704;		// Actual: 240
	rom_contents[300] = 5134;		// Actual: 94
	rom_contents[301] = 69641;		// Actual: 201
	rom_contents[302] = 66563;		// Actual: 147
	rom_contents[303] = 72704;		// Actual: 240
	rom_contents[304] = 5130;		// Actual: 90
	rom_contents[305] = 69641;		// Actual: 201
	rom_contents[306] = 72719;		// Actual: 255
	rom_contents[307] = 72704;		// Actual: 240
	rom_contents[308] = 5126;		// Actual: 86
	rom_contents[309] = 69641;		// Actual: 201
	rom_contents[310] = 13;		// Actual: 13
	rom_contents[311] = 70656;		// Actual: 208
	rom_contents[312] = 2061;		// Actual: 45
	rom_contents[313] = 67593;		// Actual: 169
	rom_contents[314] = 2048;		// Actual: 32
	rom_contents[315] = 65549;		// Actual: 141
	rom_contents[316] = 0;		// Actual: 0
	rom_contents[317] = 7183;		// Actual: 127
	rom_contents[318] = 67593;		// Actual: 169
	rom_contents[319] = 1;		// Actual: 1
	rom_contents[320] = 65541;		// Actual: 133
	rom_contents[321] = 4;		// Actual: 4
	rom_contents[322] = 71686;		// Actual: 230
	rom_contents[323] = 5;		// Actual: 5
	rom_contents[324] = 67589;		// Actual: 165
	rom_contents[325] = 5;		// Actual: 5
	rom_contents[326] = 69641;		// Actual: 201
	rom_contents[327] = 1037;		// Actual: 29
	rom_contents[328] = 70656;		// Actual: 208
	rom_contents[329] = 10;		// Actual: 10
	rom_contents[330] = 2048;		// Actual: 32
	rom_contents[331] = 5133;		// Actual: 93
	rom_contents[332] = 65539;		// Actual: 131
	rom_contents[333] = 2048;		// Actual: 32
	rom_contents[334] = 7172;		// Actual: 116
	rom_contents[335] = 65541;		// Actual: 133
	rom_contents[336] = 67593;		// Actual: 169
	rom_contents[337] = 1036;		// Actual: 28
	rom_contents[338] = 65541;		// Actual: 133
	rom_contents[339] = 5;		// Actual: 5
	rom_contents[340] = 67589;		// Actual: 165
	rom_contents[341] = 5;		// Actual: 5
	rom_contents[342] = 65549;		// Actual: 141
	rom_contents[343] = 72704;		// Actual: 240
	rom_contents[344] = 7183;		// Actual: 127
	rom_contents[345] = 67589;		// Actual: 165
	rom_contents[346] = 4;		// Actual: 4
	rom_contents[347] = 65549;		// Actual: 141
	rom_contents[348] = 72705;		// Actual: 241
	rom_contents[349] = 7183;		// Actual: 127
	rom_contents[350] = 67593;		// Actual: 169
	rom_contents[351] = 7183;		// Actual: 127
	rom_contents[352] = 65549;		// Actual: 141
	rom_contents[353] = 0;		// Actual: 0
	rom_contents[354] = 7183;		// Actual: 127
	rom_contents[355] = 4108;		// Actual: 76
	rom_contents[356] = 65547;		// Actual: 139
	rom_contents[357] = 65537;		// Actual: 129
	rom_contents[358] = 65549;		// Actual: 141
	rom_contents[359] = 0;		// Actual: 0
	rom_contents[360] = 7183;		// Actual: 127
	rom_contents[361] = 65541;		// Actual: 133
	rom_contents[362] = 6;		// Actual: 6
	rom_contents[363] = 2048;		// Actual: 32
	rom_contents[364] = 8;		// Actual: 8
	rom_contents[365] = 65538;		// Actual: 130
	rom_contents[366] = 71686;		// Actual: 230
	rom_contents[367] = 4;		// Actual: 4
	rom_contents[368] = 67593;		// Actual: 169
	rom_contents[369] = 3073;		// Actual: 49
	rom_contents[370] = 69637;		// Actual: 197
	rom_contents[371] = 4;		// Actual: 4
	rom_contents[372] = 70656;		// Actual: 208
	rom_contents[373] = 6;		// Actual: 6
	rom_contents[374] = 67593;		// Actual: 169
	rom_contents[375] = 1;		// Actual: 1
	rom_contents[376] = 65541;		// Actual: 133
	rom_contents[377] = 4;		// Actual: 4
	rom_contents[378] = 71686;		// Actual: 230
	rom_contents[379] = 5;		// Actual: 5
	rom_contents[380] = 67589;		// Actual: 165
	rom_contents[381] = 5;		// Actual: 5
	rom_contents[382] = 65549;		// Actual: 141
	rom_contents[383] = 72704;		// Actual: 240
	rom_contents[384] = 7183;		// Actual: 127
	rom_contents[385] = 67589;		// Actual: 165
	rom_contents[386] = 4;		// Actual: 4
	rom_contents[387] = 65549;		// Actual: 141
	rom_contents[388] = 72705;		// Actual: 241
	rom_contents[389] = 7183;		// Actual: 127
	rom_contents[390] = 67593;		// Actual: 169
	rom_contents[391] = 7183;		// Actual: 127
	rom_contents[392] = 65549;		// Actual: 141
	rom_contents[393] = 0;		// Actual: 0
	rom_contents[394] = 7183;		// Actual: 127
	rom_contents[395] = 6152;		// Actual: 104
	rom_contents[396] = 6144;		// Actual: 96
	rom_contents[397] = 1032;		// Actual: 24
	rom_contents[398] = 6144;		// Actual: 96
	rom_contents[399] = 67593;		// Actual: 169
	rom_contents[400] = 3;		// Actual: 3
	rom_contents[401] = 1036;		// Actual: 28
	rom_contents[402] = 71680;		// Actual: 224
	rom_contents[403] = 7183;		// Actual: 127
	rom_contents[404] = 6144;		// Actual: 96
	rom_contents[405] = 67593;		// Actual: 169
	rom_contents[406] = 2;		// Actual: 2
	rom_contents[407] = 12;		// Actual: 12
	rom_contents[408] = 71680;		// Actual: 224
	rom_contents[409] = 7183;		// Actual: 127
	rom_contents[410] = 6144;		// Actual: 96
	rom_contents[411] = 67593;		// Actual: 169
	rom_contents[412] = 3;		// Actual: 3
	rom_contents[413] = 12;		// Actual: 12
	rom_contents[414] = 71680;		// Actual: 224
	rom_contents[415] = 7183;		// Actual: 127
	rom_contents[416] = 6144;		// Actual: 96
	rom_contents[417] = 67593;		// Actual: 169
	rom_contents[418] = 1;		// Actual: 1
	rom_contents[419] = 65549;		// Actual: 141
	rom_contents[420] = 71681;		// Actual: 225
	rom_contents[421] = 7183;		// Actual: 127
	rom_contents[422] = 2048;		// Actual: 32
	rom_contents[423] = 66571;		// Actual: 155
	rom_contents[424] = 65537;		// Actual: 129
	rom_contents[425] = 2048;		// Actual: 32
	rom_contents[426] = 65551;		// Actual: 143
	rom_contents[427] = 65537;		// Actual: 129
	rom_contents[428] = 67593;		// Actual: 169
	rom_contents[429] = 0;		// Actual: 0
	rom_contents[430] = 65549;		// Actual: 141
	rom_contents[431] = 71681;		// Actual: 225
	rom_contents[432] = 7183;		// Actual: 127
	rom_contents[433] = 2048;		// Actual: 32
	rom_contents[434] = 66565;		// Actual: 149
	rom_contents[435] = 65537;		// Actual: 129
	rom_contents[436] = 2048;		// Actual: 32
	rom_contents[437] = 65551;		// Actual: 143
	rom_contents[438] = 65537;		// Actual: 129
	rom_contents[439] = 67593;		// Actual: 169
	rom_contents[440] = 3;		// Actual: 3
	rom_contents[441] = 65549;		// Actual: 141
	rom_contents[442] = 71681;		// Actual: 225
	rom_contents[443] = 7183;		// Actual: 127
	rom_contents[444] = 2048;		// Actual: 32
	rom_contents[445] = 66571;		// Actual: 155
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

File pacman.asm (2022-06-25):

;;;;
; Vectron 65 Plus Graphic Demo
;
; Nick Bild
; nick.bild@gmail.com
; June 2022
;
; Reserved memory:
;
; $0000-$7EFF - RAM
; 		$0000-$0010 - Named variables
; 		$0100-$01FF - 6502 stack
; $7FE0-$7FEF - 6522 VIA 2
; $7FF0-$7FFF - 6522 VIA 1
; $8000-$FFFF - ROM
; 		$FFFA-$FFFB - NMI IRQ Vector
; 		$FFFC-$FFFD - Reset Vector - Stores start address of this ROM.
; 		$FFFE-$FFFF - IRQ Vector
;;;;

		processor 6502

		; Named variables in RAM.
		ORG $0000
addrLow
		.byte #$00
addrMid
		.byte #$00
addrHigh
		.byte #$00
data
		.byte #$00
eyeLow
		.byte #$00
eyeMid
		.byte #$00
eyeHigh
		.byte #$00
ghostColor
		.byte #$00


StartExe	ORG $8000
	cld
	sei						; Disable interrupts.

  ; Set up VIAs.

  ; Disable all VIA interrupts in IER.
	lda #$7F
	sta $7FFE
    sta $7FEE

	; Set DDRB to all outputs.
	lda #$FF
	sta $7FF2

	; Set DDRA to all outputs.
	lda #$FF
	sta $7FF3

	; Set DDRB to all outputs.
	lda #$FF
	sta $7FE2

	; Set DDRA to all outputs.
	lda #$FF
	sta $7FE3

	; Write blank VGA signal to both RAM chips.

	; Set Vectron VGA Plus memory counter to 0.
	lda #$00
	sta addrLow
	sta addrMid
	sta addrHigh

	; Set inital state of WE/CE on Vectron VGA Plus.
	; CE/WE high
  	lda #$03
  	.byte #$0C ; tsb - set bit
  	.word #$7FE0
  	
	; Write VGA signal timings for a blank screen to memory.
	jsr SetupVGA

	; CE low (read mode)
  	; WE high
  	lda #$01
  	.byte #$0C ; tsb - set bit
	.word #$7FE0
  	; CE low
  	lda #$02
  	.byte #$1C ; trb - clear bit
	.word #$7FE0


	; Set Vectron VGA Plus memory counter to 0.
	lda #$00
	sta addrLow
	sta addrMid
	sta addrHigh

	; Set inital state of WE/CE on Vectron VGA Plus.
	; CE/WE high
	lda #$03
  	.byte #$0C ; tsb - set bit
  	.word #$7FE0
  	
	; Write VGA signal timings for a blank screen to memory.
	jsr SetupVGA

	; CE low (read mode)
  	; WE high
  	lda #$01
  	.byte #$0C ; tsb - set bit
	.word #$7FE0
  	; CE low
  	lda #$02
  	.byte #$1C ; trb - clear bit
	.word #$7FE0

	;;; Draw ghost 1.

	lda #$19
	sta ghostColor

	lda #$71
	sta addrLow
	lda #$1F
	sta addrMid
	lda #$00
	sta addrHigh

	lda #$1D
	sta eyeLow
	lda #$61
	sta eyeMid
	lda #$00
	sta eyeHigh

	; CE/WE high
	lda #$03
  	.byte #$0C ; tsb - set bit
  	.word #$7FE0

	jsr DrawGhost

	; CE low (read mode)
  	; WE high
  	lda #$01
  	.byte #$0C ; tsb - set bit
	.word #$7FE0
  	; CE low
  	lda #$02
  	.byte #$1C ; trb - clear bit
	.word #$7FE0

	lda #$19
	sta ghostColor

	lda #$71
	sta addrLow
	lda #$1F
	sta addrMid
	lda #$00
	sta addrHigh

	lda #$1D
	sta eyeLow
	lda #$61
	sta eyeMid
	lda #$00
	sta eyeHigh

	; CE/WE high
	lda #$03
  	.byte #$0C ; tsb - set bit
  	.word #$7FE0

	jsr DrawGhost

	; CE low (read mode)
  	; WE high
  	lda #$01
  	.byte #$0C ; tsb - set bit
	.word #$7FE0
  	; CE low
  	lda #$02
  	.byte #$1C ; trb - clear bit
	.word #$7FE0

	;;; Draw ghost 2.

	lda #$1E
	sta ghostColor

	lda #$2F
	sta addrLow
	lda #$20
	sta addrMid
	lda #$00
	sta addrHigh

	lda #$DB
	sta eyeLow
	lda #$61
	sta eyeMid
	lda #$00
	sta eyeHigh

	; CE/WE high
	lda #$03
  	.byte #$0C ; tsb - set bit
  	.word #$7FE0

	jsr DrawGhost

	; CE low (read mode)
  	; WE high
  	lda #$01
  	.byte #$0C ; tsb - set bit
	.word #$7FE0
  	; CE low
  	lda #$02
  	.byte #$1C ; trb - clear bit
	.word #$7FE0

	lda #$1E
	sta ghostColor

	lda #$2F
	sta addrLow
	lda #$20
	sta addrMid
	lda #$00
	sta addrHigh

	lda #$DB
	sta eyeLow
	lda #$61
	sta eyeMid
	lda #$00
	sta eyeHigh

	; CE/WE high
	lda #$03
  	.byte #$0C ; tsb - set bit
  	.word #$7FE0

	jsr DrawGhost

	; CE low (read mode)
  	; WE high
  	lda #$01
  	.byte #$0C ; tsb - set bit
	.word #$7FE0
  	; CE low
  	lda #$02
  	.byte #$1C ; trb - clear bit
	.word #$7FE0

	;;; Draw ghost 3.

	lda #$1A
	sta ghostColor

	lda #$C1
	sta addrLow
	lda #$5F
	sta addrMid
	lda #$01
	sta addrHigh

	lda #$6D
	sta eyeLow
	lda #$A1
	sta eyeMid
	lda #$01
	sta eyeHigh

	; CE/WE high
	lda #$03
  	.byte #$0C ; tsb - set bit
  	.word #$7FE0

	jsr DrawGhost

	; CE low (read mode)
  	; WE high
  	lda #$01
  	.byte #$0C ; tsb - set bit
	.word #$7FE0
  	; CE low
  	lda #$02
  	.byte #$1C ; trb - clear bit
	.word #$7FE0

	lda #$1A
	sta ghostColor

	lda #$C1
	sta addrLow
	lda #$5F
	sta addrMid
	lda #$01
	sta addrHigh

	lda #$6D
	sta eyeLow
	lda #$A1
	sta eyeMid
	lda #$01
	sta eyeHigh

	; CE/WE high
	lda #$03
  	.byte #$0C ; tsb - set bit
  	.word #$7FE0

	jsr DrawGhost

	; CE low (read mode)
  	; WE high
  	lda #$01
  	.byte #$0C ; tsb - set bit
	.word #$7FE0
  	; CE low
  	lda #$02
  	.byte #$1C ; trb - clear bit
	.word #$7FE0

	;;; Draw ghost 4.

	lda #$1D
	sta ghostColor

	lda #$7F
	sta addrLow
	lda #$60
	sta addrMid
	lda #$01
	sta addrHigh

	lda #$2B
	sta eyeLow
	lda #$A2
	sta eyeMid
	lda #$01
	sta eyeHigh

	; CE/WE high
	lda #$03
  	.byte #$0C ; tsb - set bit
  	.word #$7FE0

	jsr DrawGhost

	; CE low (read mode)
  	; WE high
  	lda #$01
  	.byte #$0C ; tsb - set bit
	.word #$7FE0
  	; CE low
  	lda #$02
  	.byte #$1C ; trb - clear bit
	.word #$7FE0

	lda #$1D
	sta ghostColor

	lda #$7F
	sta addrLow
	lda #$60
	sta addrMid
	lda #$01
	sta addrHigh

	lda #$2B
	sta eyeLow
	lda #$A2
	sta eyeMid
	lda #$01
	sta eyeHigh

	; CE/WE high
	lda #$03
  	.byte #$0C ; tsb - set bit
  	.word #$7FE0

	jsr DrawGhost

	; CE low (read mode)
  	; WE high
  	lda #$01
  	.byte #$0C ; tsb - set bit
	.word #$7FE0
  	; CE low
  	lda #$02
  	.byte #$1C ; trb - clear bit
	.word #$7FE0


MainLoop
    jmp MainLoop


;;;;
; Set up a blank VGA display.
;;;;


SetupVGA
	; Visible lines and vertical front porch.

	; 489 * visible line.
	ldy #$FF
SetupVGA1
	jsr DrawVisibleLine
	dey
	bne SetupVGA1

	ldy #$EA
SetupVGA2
	jsr DrawVisibleLine
	dey
	bne SetupVGA2

	; Vertical sync.
	jsr VSync

	; vertical back porch
	ldy #$21
SetupVGA3
	jsr DrawVisibleLine
	dey
	bne SetupVGA3

	; Finish last row.
	lda #$18		; 24
	sta data

	ldy #$10
SetupVGA4
	jsr WriteData
  jsr IncAddress
	dey
	bne SetupVGA4
	
	rts


DrawVisibleLine
	.byte #$DA ; phx - mnemonic unknown to DASM.
	.byte #$5A ; phy

	; 328 * 24;  48 * 16;  24 * 24
	
	lda #$18		; 24
	sta data

	ldx #$FF
Visible1
	jsr WriteData
  jsr IncAddress
	dex
	bne Visible1

	ldx #$49
Visible2
	jsr WriteData
  jsr IncAddress
	dex
	bne Visible2

	lda #$10		; 16
	sta data

	ldx #$30
Visible3
	jsr WriteData
  jsr IncAddress
	dex
	bne Visible3

	lda #$18		; 24
	sta data

	ldx #$18
Visible4
	jsr WriteData
  jsr IncAddress
	dex
	bne Visible4
 
	.byte #$7A ; ply
	.byte #$FA ; plx

	rts
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

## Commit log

2020-12-16 Switch WAV write method.
2021-09-12 Fix timing on block write.
    [rpi_sd_poc.py]
2021-11-05 Add TeensyROM build code.
2022-02-17 Fix BASIC output timings and pad character.
    [os_vvga.asm]
2022-02-21 Resize screen and fix backspace.
    [os_vvga.asm]
2022-02-22 Speed up screen redraws by skipping identical characters.
    [os_vvga.asm]
2022-05-02 Save progress on schematic.
    [kicad_vectron_65_plus.kicad_pcb, kicad_vectron_65_plus.sch]
2022-05-09 Update schematic.
    [kicad_vectron_65_plus.sch]
2022-05-13 Save progress on PCB.
    [kicad_vectron_65_plus.kicad_pcb]
2022-06-15 Mirror image for PS/2 connection.
    [kicad_vectron_65_plus.kicad_pcb, kicad_vectron_65_plus.sch]
2022-06-16 Switch to using controller.

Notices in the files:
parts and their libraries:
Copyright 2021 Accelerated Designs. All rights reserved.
